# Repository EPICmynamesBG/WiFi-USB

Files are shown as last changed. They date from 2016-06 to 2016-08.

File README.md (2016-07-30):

# WiFi-USB #
A wirelessly controllable USB power port

_Firmware Version:_ 1.2

_iOS App Version_: 0.4

_Web App Version_: 0.2

---

## About ##

_What is WiFi-USB?_

WiFi-USB is an IoT device and software that enables a USB powered device (up to 2.0 A) to be remotely powered on and off.

_Why WiFi-USB?_

The inspiration for this project came from a general irritation with a USB powered device that did not have an inline power switch. Wall outlets aren't always in the most convenient of places, so plugging/unplugging this USB port from a wall adapter all the time could be a hassle.

_How can I use WiFi-USB?_

Keep reading below for more on how to build your own WiFi-USB board, and instructions on how to install the firmware to get your device up and running.

## Examples/Usage ##

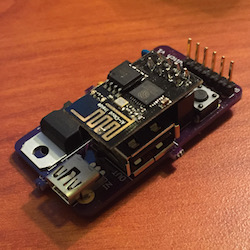
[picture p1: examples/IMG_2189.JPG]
WiFi-USB 1

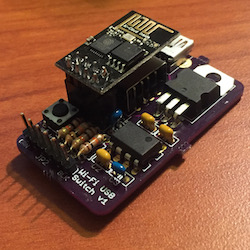
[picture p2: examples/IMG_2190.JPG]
WiFi-USB 2

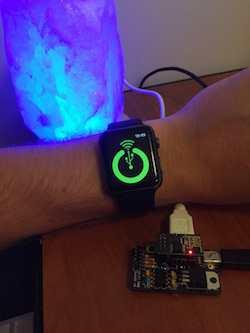
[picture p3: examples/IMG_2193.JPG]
WiFi-USB Watch 1

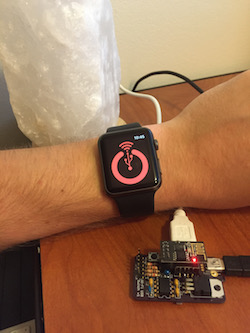
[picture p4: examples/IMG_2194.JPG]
WiFi-USB Watch 2

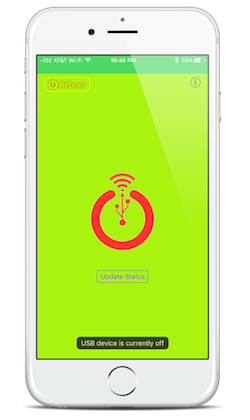
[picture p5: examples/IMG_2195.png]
WiFi-USB iOS 1

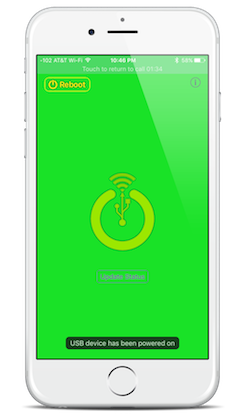
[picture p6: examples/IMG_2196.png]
WiFi-USB iOS 2


## Important Notes ##

** Never plug both the mini-USB power supply and the FTDI power at the same time. The hardware is not designed to handle this and will surely break **

## Recent Updates ##

### Firmware v1.2 ###

- Introducing Access Point Broadcasting fallback when client connect mode fails

## Hardware ##

Files and instructions will be posted soon.

## Firmware Install ##

1. Download and install the [Arduino IDE](https://www.arduino.cc/en/Main/Software)
2. Configure the IDE using the instructions [here](https://github.com/esp8266/arduino#installing-with-boards-manager)
3. Download the zip/clone this repo
4. In `config.h` update the SSID and SSID_PASSWORD variables to match your network configuration.
5. Open `firmware.ino` and click upload in the Arduino IDE when the device is in develop mode

## Web Install ##

The appropriate web files are already in the WiFi-USB's firmware > data folder. Simply follow [this guide](https://github.com/esp8266/arduino-esp8266fs-plugin) on how to install and upload the those files to WiFi-USB for the web control panel to become available.

## Installing the iOS & Watch app (Requires a Mac) ##

1. Install [XCode](https://itunes.apple.com/us/app/xcode/id497799835?mt=12) on your system
  - Built using XCode 7.3.1
2. Open  WiFi-USB.xcodeproj
3. Select the Project (the blue icon) from the Nvigation bar
  - Under Targets, change the team on each one to the team of your desire (probably personal or None)
4. Now plug in your device, and click the Play arrow to Run the app on your device
  - If you have a watch, to install the watch app, on the bar next to the run button, select WK-WiFi-USB as your build target, then selecte your device with watch, and hit Run 

## Using WiFi-USB ##

The default endpoint for WiFi-USB will be [http://wifiusb.local](http://wifiusb.local). Going to this page will show you a simple html page, confirming that the wifiusb is running.

WiFi-USB is configured with 3 REST endpoints that will return JSON data:

_Check the status of the USB's power_
* `/status` - GET (no parameters)
  * `on: Bool` - simple check if USB is on or off
  * `raw: Int` - the raw GPIO pin value for the USB pin 
  * `description: String` - a textual description of the USB power status

_Toggle the USB power on/off_
* `/toggle` - POST (no parameters)
  * `on: Bool` - simple check if USB is on or off
  * `raw: Int` - the raw GPIO pin value for the USB pin 
  * `description: String` - a textual description of the USB power status

_Reboot the device_
* `/reboot` - GET (no parameters)
  * `description: String` - a textual confirmation that the device is rebooting

## Future Ideas ##
* Add a timer/alarm clock ability. Turn on/off at a set time!
* ~~Create an Apple Watch extensnion ~~
* Add WebSocket ability for live status sync across all controller devices

## Credits ##

[Alex Cordonnier](https://github.com/ajcord) - for designing the board and helping me troubleshoot every step of the way!

## Licenses ##

[_firmware_](https://github.com/EPICmynamesBG/WiFi-USB/blob/master/firmware/LICENSE) : GNU GPLv3

[_iOS_](https://github.com/EPICmynamesBG/WiFi-USB/blob/master/iOS/LICENSE) : GNU GPLv3

[_iOS_](https://github.com/EPICmynamesBG/WiFi-USB/blob/master/web/LICENSE) : GNU GPLv3

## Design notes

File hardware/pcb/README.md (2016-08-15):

# WiFi-USB PCB v3

This folder contains the Eagle CAD files for the WiFi-USB circuit board.

To install Eagle with a free Express or Educational license, go to
https://cadsoft.io.

It also contains a PDF of the schematic and an image of the board layout
if you want to view the design without installing Eagle.

## Parts

These saved cart links include all the parts necessary to build one board.

* DigiKey: http://www.digikey.com/short/3mnpbh
* Mouser: http://www.mouser.com/ProjectManager/ProjectDetail.aspx?AccessID=066B4F095A
* Sparkfun: https://www.sparkfun.com/products/9717
    - This cable is reusable for many other kinds of projects.
      It is possible to use an alternative to avoid buying an expensive new
      cable, as long as the Tx and Rx signals are 3.3V. The ESP8266 may get
      fried by 5V signals. However, Vcc goes through the voltage regulator and
      is therefore 5V tolerant.

## Fabrication

I recommend ordering PCBs through [OSH Park](https://oshpark.com).
It only costs about $11 for 3 copies of this board, the quality is good,
and they come in a very regal purple and gold.
There are of course many other options you may prefer, but for newcomers,
OSH Park is recommended.

## Building

TODO (Brandon): add build instructions/hints

## Mounting

The mounting holes on the PCB are 2.79mm in diameter, designed to fit
M2.5 screws. These mounting holes are not grounded in the interest of
saving board space.

## Changelog (v3):
* Redesigned form factor to be longer and thinner with receptacles on
  opposite sides
* Added mounting holes
* Removed USB data connection &mdash; only passes through power now
* Grounded USB receptacle chassis
* Added pads around USB-A mounting holes and voltage regulator heatsink
* Eliminated some unnecessary resistors
* Added OSHW logo

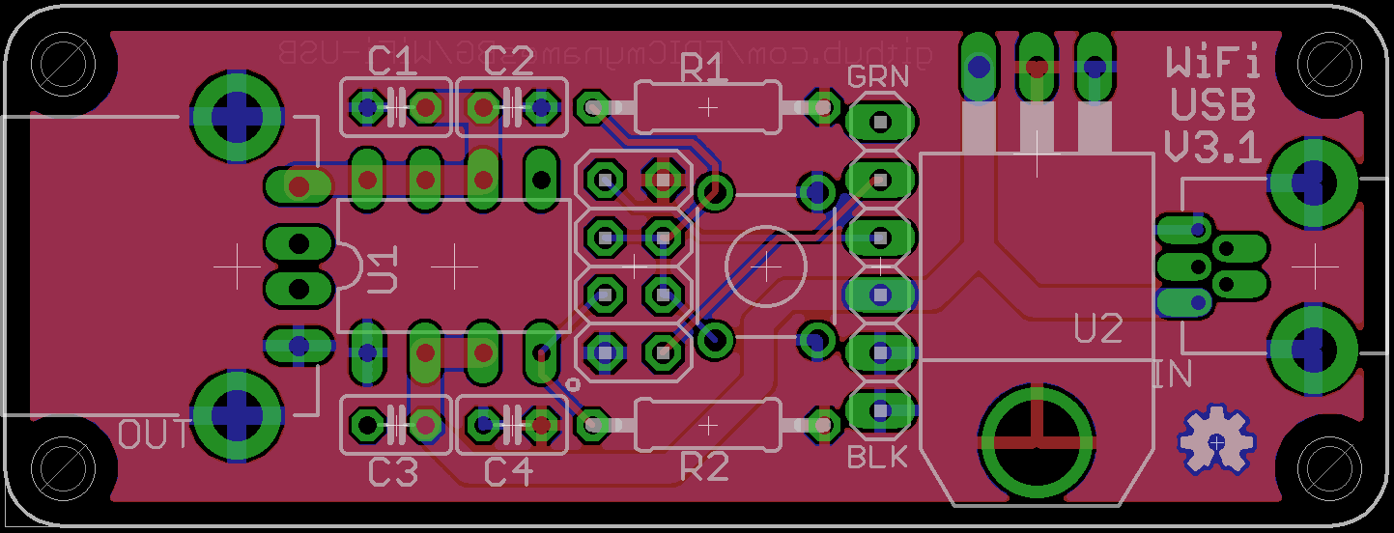
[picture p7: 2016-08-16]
hardware/pcb/board.png

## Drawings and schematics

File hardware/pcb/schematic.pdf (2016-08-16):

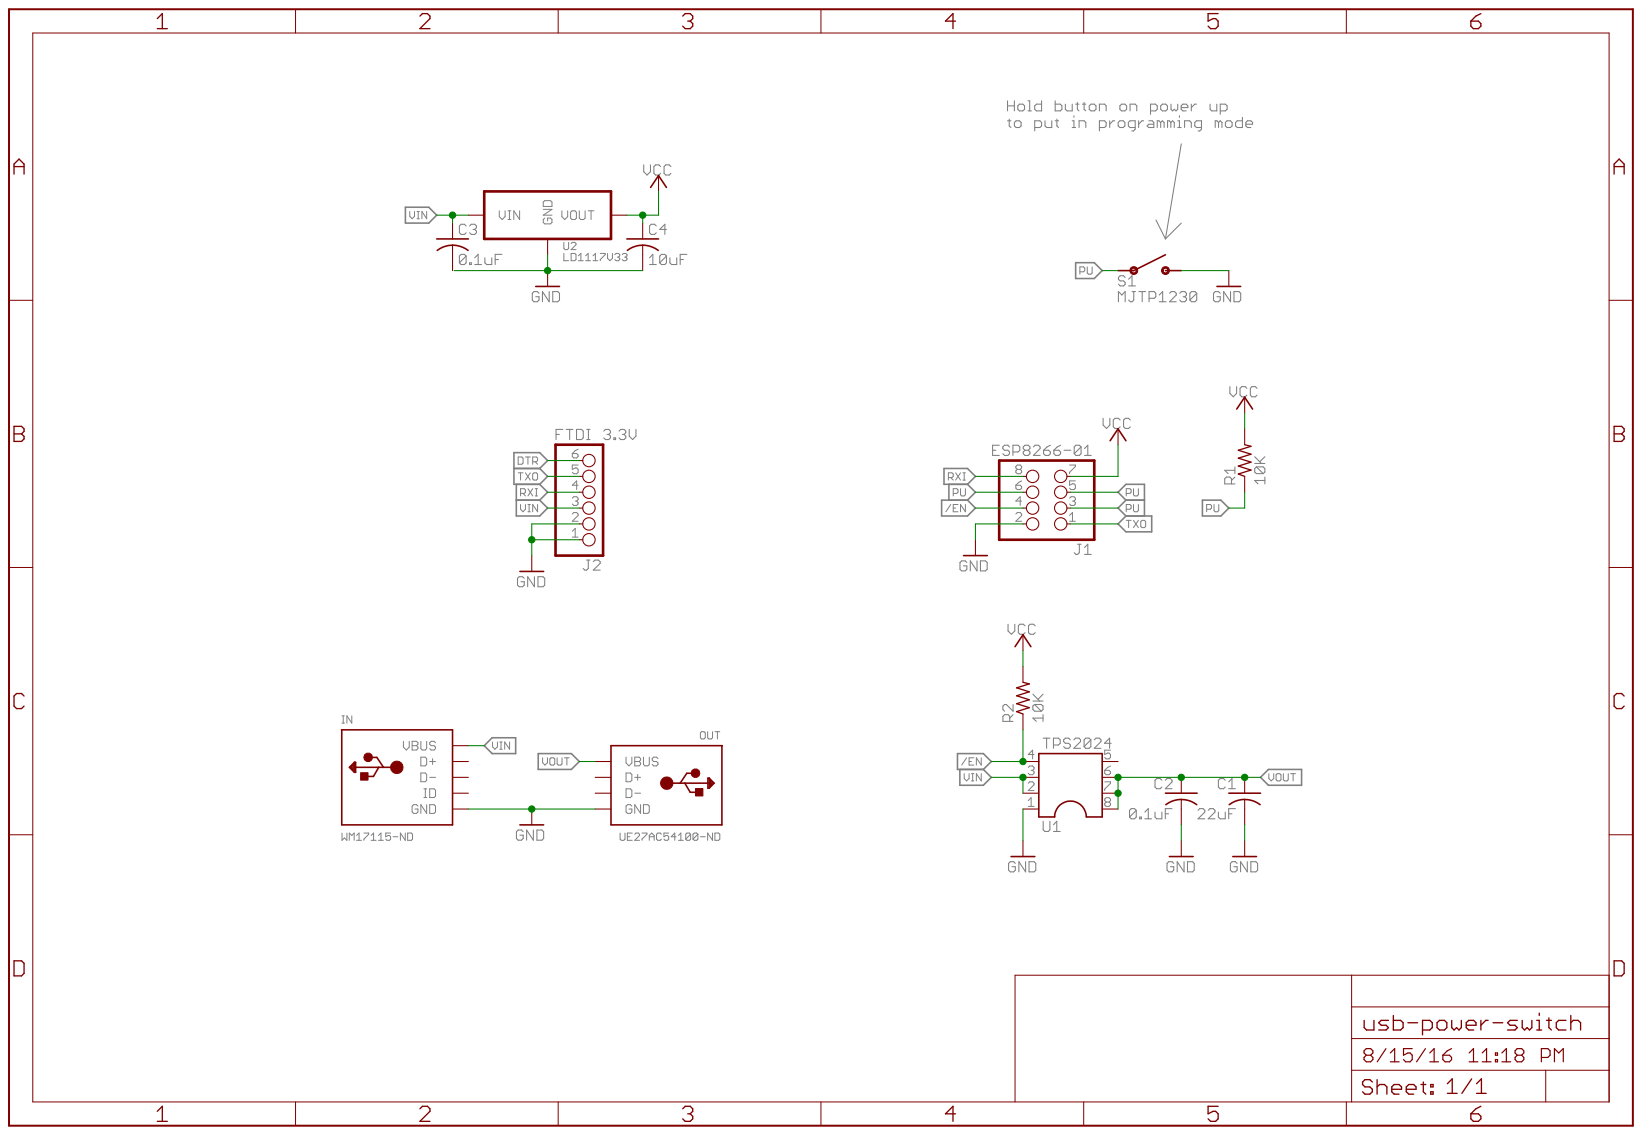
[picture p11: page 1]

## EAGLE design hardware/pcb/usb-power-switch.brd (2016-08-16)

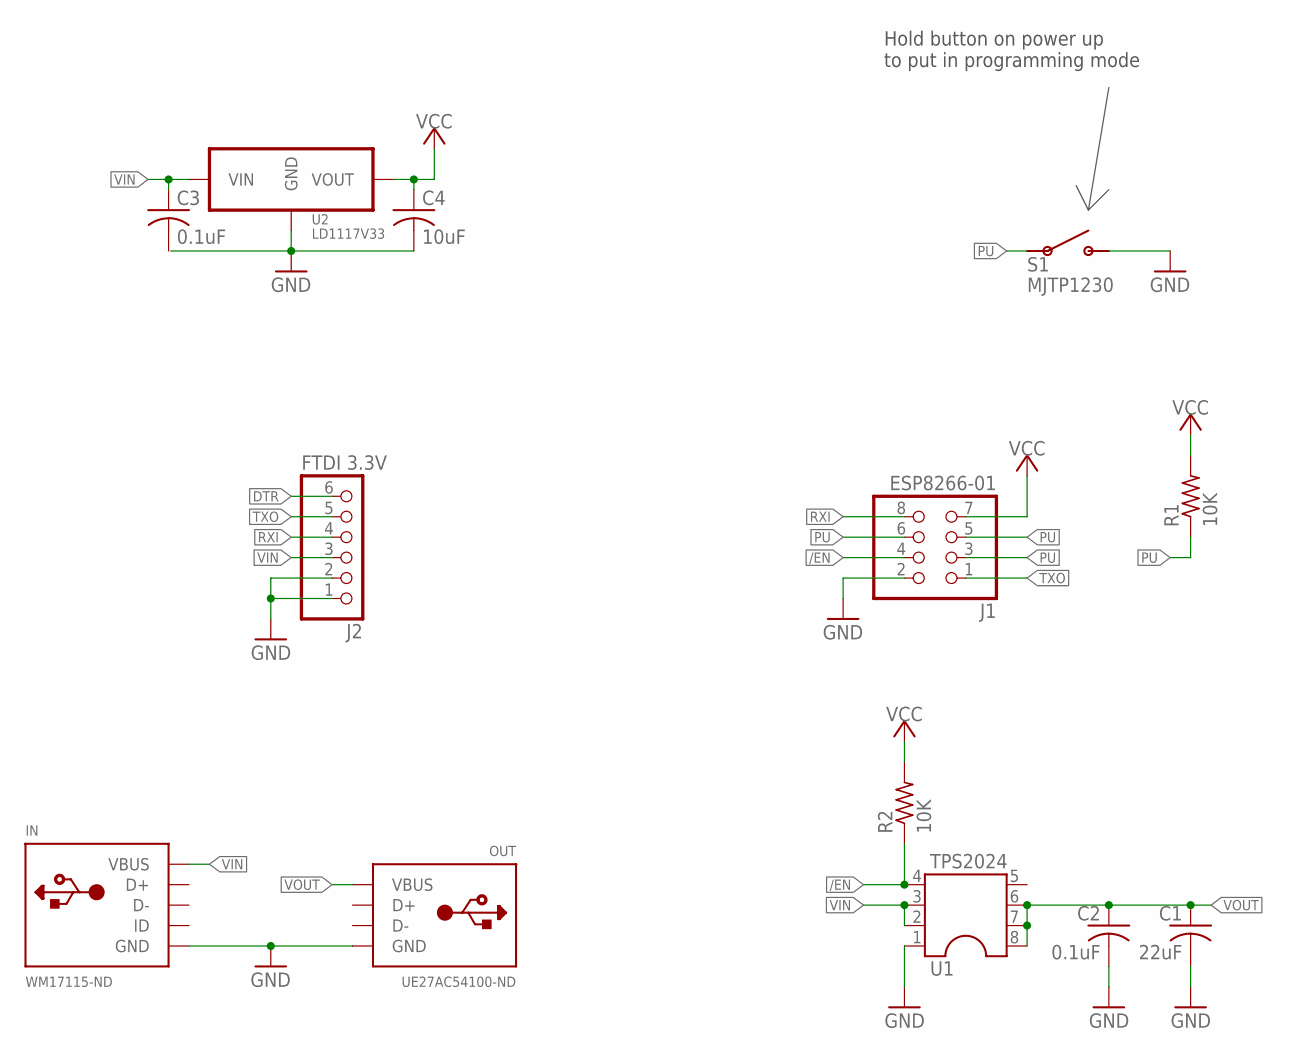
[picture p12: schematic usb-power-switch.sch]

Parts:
C1: 22uF; C025-025X050
C2, C3: 0.1uF; C025-025X050
C4: 10uF; C025-025X050
IN: WM17115-ND; USB-MINI-B
J1: ESP8266-01; 2X04
J2: FTDI 3.3V; 1X06
OUT: UE27AC54100-ND; USB-A
R1, R2: 10K; 0207/10
S1: MJTP1230; TACTILE-BUTTON-MJTP1230
U1: TPS2024; DIL08
U2: LD1117V33; TO-220

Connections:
/EN: J1.4, R2.1, U1.4
DTR: J2.6
GND: C1.2, C2.2, C4.2, IN.GND, IN.GND1 (GND), IN.GND4 (GND), J1.2, J2.1, J2.2, OUT.P$4 (GND), OUT.P$5 (GND), OUT.P$6 (GND), S1.P$2 (3), S1.P$4 (3), U1.1, U2.P$1 (GND)
PU: J1.3, J1.5, J1.6, R1.1, S1.P$1 (1), S1.P$3 (1)
RXI: J1.8, J2.4
TXO: J1.1, J2.5
VCC: C4.1, J1.7, R1.2, R2.2, U2.P$2 (VOUT), U2.P$4 (VOUT)
VIN: C3.1, IN.VBUS, J2.3, U1.2, U1.3, U2.P$3 (VIN)
VOUT: C1.1, C2.1, OUT.P$1 (VBUS), U1.6, U1.7, U1.8

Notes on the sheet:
Hold button on power up to put in programming mode

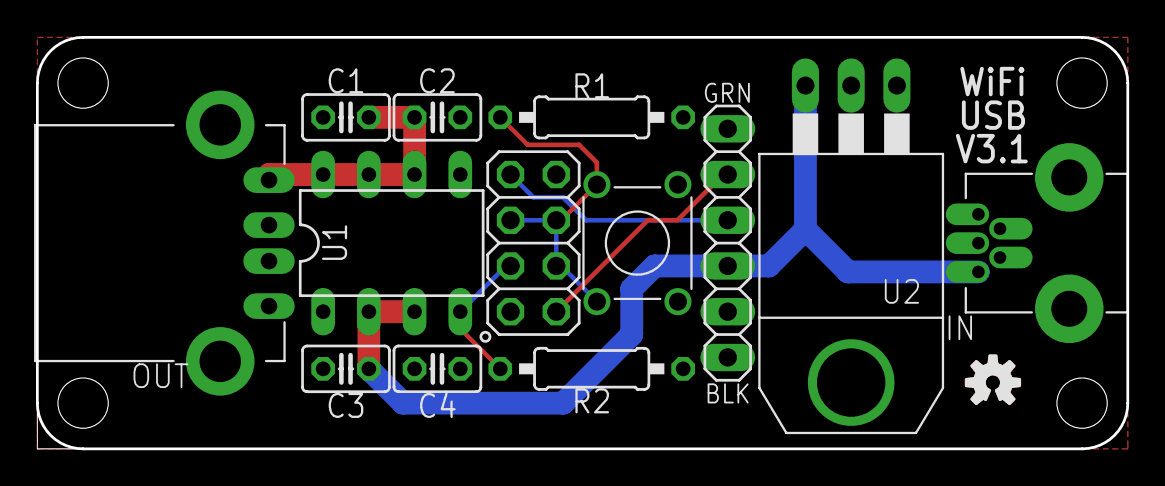
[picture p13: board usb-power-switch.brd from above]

Board: 2 copper layers, 60.6 x 22.9 mm, 15 parts (0 on the bottom side), 8 nets.

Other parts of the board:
U$1: OSHW-LOGO-S
U$2: OSHW-LOGO-S_COPPER

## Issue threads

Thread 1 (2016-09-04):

Look into potential RST/GPIO0 shared pullup issue

ajcord, 2016-09-04:
Sharing the pullup might not work because when the button is released, both RST and GPIO0 will go high again, so GPIO0 will not necessarily be low for long enough on power up. Look into adding a small (maybe 100nF) capacitor on GPIO0, or not sharing the pullup.

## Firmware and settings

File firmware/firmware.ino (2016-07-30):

/**
* WiFi-USB: a wirelessly controllable USB power port
* Author: Brandon Groff
* Version: 1.2
* License: GNU GPLv3 (see LICENSE)
*/

#include <ESP8266WiFi.h>
#include "src/config.h"
#include "src/USBPower.h"
#include "src/WiFiUSBWebServer.h"

void setup() {
    
    initialize();
    
    printMacAddress();
    if (establishWirelessConnection()){
        printWirelessClientInfo();
    } else {
        Serial.print("\n\nConnecting to network "+String(SSID)+" failed. Going into Access Point mode...");
        setupAccessPointMode();
        printWirelessBroadcastInfo();
    }
    
    
    WebServer.begin();
    
}

void loop() {
    
    WebServer.handleClients();
    
}

/**
* Setup Serial printing and GPIO pins
*/
void initialize() {
    Serial.begin(115200);
    Serial.print("\n\n");

    pinMode(USB_PIN, OUTPUT);
    digitalWrite(USB_PIN, 0);
}

/**
 * Print the ESP8266's MAC address
 */
void printMacAddress() {

    Serial.print("MAC address: ");

    unsigned char mac[WL_MAC_ADDR_LENGTH];
    WiFi.macAddress(mac);

    for (int i = WL_MAC_ADDR_LENGTH - 1; i > 0; i--) {
        Serial.print(mac[i], HEX);
        Serial.print(":");
    }

    Serial.println(mac[0], HEX);
}

/**
 * Print info about the wireless connection.
 */
void printWirelessClientInfo() {

    Serial.print("LAN IPv4 address: ");
    Serial.println(WiFi.localIP());

    Serial.print("Signal strength (RSSI): ");
    Serial.println(WiFi.RSSI());
}

bool establishWirelessConnection() {
    
    Serial.print("\n\nAttempting to establish a wireless connection to " + String(SSID) + "\n");
    WiFi.begin(SSID, SSID_PASSWORD);
    
    int connectAttempts = 0;
    while (WiFi.status() != WL_CONNECTED) {
        if (connectAttempts > 10){
            WiFi.disconnect(true);
            return false;
            break;
        }
        
        delay(1000);
        Serial.print(".");
        connectAttempts += 1;
    }
    
    Serial.println("Connected to " + String(SSID));
    return true;
}

void setupAccessPointMode() {
    Serial.print("\n\nConfiguring access point...\n");
    WiFi.softAP(AP_SSID, AP_PASSWORD);
}

void printWirelessBroadcastInfo() {
    Serial.print("Access Point IPv4 address: ");
    Serial.println(WiFi.softAPIP());
    
    Serial.println("Access Point started.");
    Serial.println("SSID: "+ String(AP_SSID));
    Serial.println("Password: "+ String(AP_PASSWORD));
    
}

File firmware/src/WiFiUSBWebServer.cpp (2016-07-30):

/**
* WiFi-USB: a wirelessly controllable USB power port
* Author: Brandon Groff
* Version: 1.2
* License: GNU GPLv3 (see LICENSE)
*/

#include "WiFiUSBWebServer.h"
#include "config.h"
#include "FS.h"

WiFiUSBWebServer::WiFiUSBWebServer() 
    : server(80) { };
            

void WiFiUSBWebServer::begin() {
    
    mdns.begin(WEBSERVER_DOMAIN, WiFi.localIP());
    
    SPIFFS.begin();
    
    server.serveStatic("/", SPIFFS, "/index.html", "max-age=86400");
    server.serveStatic("/index.css", SPIFFS, "/index.css", "max-age=86400");
    server.serveStatic("/index.js", SPIFFS, "/index.js", "max-age=86400");
    server.serveStatic("/images/favicon.png", SPIFFS, "/favicon.png", "max-age=86400");
    server.serveStatic("/images/info-icon.png", SPIFFS, "/info-icon.png", "max-age=86400");
    server.serveStatic("/images/power_button_gray_512.png", SPIFFS, "/power_button_gray_512.png", "max-age=86400");
    server.serveStatic("/images/power_button_green_512.png", SPIFFS, "/power_button_green_512.png", "max-age=86400");
    server.serveStatic("/images/power_button_red_512.png", SPIFFS, "/power_button_red_512.png", "max-age=86400");
    server.serveStatic("/images/reboot-button-web_64.png", SPIFFS, "/reboot-button-web_64.png", "max-age=86400");
    server.serveStatic("/images/app-icon.png", SPIFFS, "/app-icon.png", "max-age=86400");
    
    server.on("/status", HTTP_GET, [this] {
        handleStatus();
    });
    
    server.on("/toggle", HTTP_POST, [this]{
        handleToggle();
    });
    
    server.on("/reboot", [this] {
        handleReboot();
    });
    
    server.begin();
    Serial.println("Web server is running at http://" + String(WEBSERVER_DOMAIN) + ".local");
}

void WiFiUSBWebServer::handleClients() {
    server.handleClient();
}

void WiFiUSBWebServer::handleStatus() {

    int raw = powerManager.rawValue();
    String description = "";
    if (powerManager.isOn()) {    
        description = "USB device is powererd on";
    } else {
        description = "USB device is currently off";
    }
    
    String json = buildJSON(raw, description);
    server.send(200, "application/json", json);
}

void WiFiUSBWebServer::handleToggle() {
    powerManager.togglePower();
    int raw = powerManager.rawValue();
    String description = "";
    
    if (powerManager.isOn()) {    
        description = "USB device has been powered on";
    } else {
        description = "USB device has been powered off";
    }
    
    String json = buildJSON(raw, description);
    server.send(200, "application/json", json);
}

void WiFiUSBWebServer::handleReboot() {
    String json = "{\"description\": \"Rebooting NOW\"}";
    server.send(200, "application/json", json);
    Serial.println("System is rebooting NOW");
    ESP.restart();
}

String WiFiUSBWebServer::buildJSON(int rawValue, String description) {
    String json = "{";
    String boolString = powerManager.isOn() ? "true" : "false";
    
    json.concat("\"on\":" + boolString + ", ");
    json.concat("\"raw\":" + String(rawValue) + ", ");
    json.concat("\"description\": \"" + description  + "\"");
    
    json.concat("}");
    
    return json;
}

WiFiUSBWebServer WebServer;

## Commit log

2016-06-23 Bug/syntax/spelling fixes. Working product!
    [USBPower.cpp, WiFiUSBWebServer.cpp, firmware.ino]
2016-06-25 Update background rainbow effect, custom PowerButton with animations
2016-06-26 Updated image, set power icon as template to enable masking
2016-06-26 Custom UI object creation, replace PowerButton with Glowing Button and Gradient Button
2016-06-26 Update glow colors, update networker to handle no network connection case better
2016-06-26 Update version, add app close/resume support. Stops/starts animations, refeshes power status
2016-06-27 Skeleton, background animation, reboot button with animation, power button with animation
2016-06-29 Fix power button click, base JS functionality
2016-07-03 Actually calculated the max current
    The TPS2024 has a maximum recommended current of 2A. The power traces are 50 mil, so assuming 1oz copper, 2A would cause a 23ºC temperature rise. At room temperature, that would heat the traces to ar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
2016-07-07 Resolve issue of app not running on physical device
2016-08-14 Added PCB design
    [usb-power-switch.brd, usb-power-switch.sch]
2016-08-15 Updated PCB to v3
    [usb-power-switch.brd, usb-power-switch.sch]
2016-08-16 Optimized routing, added repo URL
    [usb-power-switch.brd, usb-power-switch.sch]

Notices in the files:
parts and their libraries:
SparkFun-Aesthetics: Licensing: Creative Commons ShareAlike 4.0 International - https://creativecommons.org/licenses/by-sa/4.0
